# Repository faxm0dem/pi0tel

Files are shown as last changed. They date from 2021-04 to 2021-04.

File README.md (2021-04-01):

# 3615 pi0

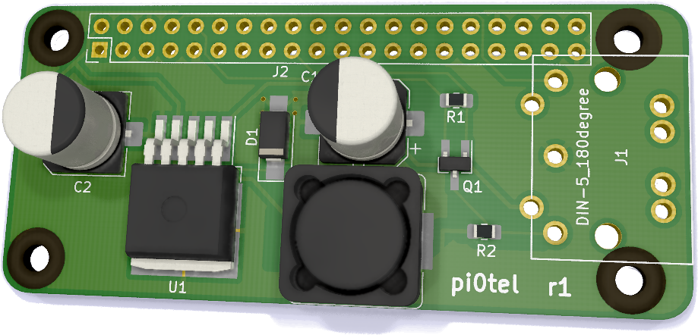
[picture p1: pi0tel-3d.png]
3D Render of the pi0tel pcb


This uHat is designed to plug on top of a pi0 or pi0-w.
It's designed to plug to the DIN-5 at the back of a Minitel-2.
The pi0 will be powered by the Minitel through the Buck converter on
the hat. TX and RX will be level-shifted to the right level on the pi's UART.

The aim is to plug the resulting dongle into a Minitel, and get instant linux.

3615 pi0 (or shall we say, 31415 Minitel).

# Reference

* https://niteshbharadwaj.github.io/posts/raspi_from_battery.html
* http://pila.fr/wordpress/?p=361
* http://www.jelora.fr/post/2020/02/25/Adaptateur-prise-DIN-peri-informatique-Minitel-vers-Serie-RS232-et-Serie-USB.html
* https://www.ti.com/lit/ds/symlink/lm2596.pdf
* https://www.edn.com/pcb-layout-tips-for-thermal-vias/
* https://www.instructables.com/id/Arduino-to-RPi-three-ways-to-convert-5-volts-to-33/
* https://randomnerdtutorials.com/how-to-level-shift-5v-to-3-3v/

# Notes

* Cin and Cout
  - should both have short leads to lm2596
  - should both have low ESR (e.g. high V rating, Nichicon PL, 1.25*Vin = 10V)
  - Ripple current rating 50% of DC load (500mA in our case)
* Cin 270uF or 330uF
* Cout 470/25 Pana or 560/16 Nichi
* Diode
  - current rating = 1.3*load = 800mA
  - reverse V rating = 1.25*Vinmax = 10V
* Heat pad should at least be 0.4"²
* L choice see page 20 of Datasheet
  - L21/L22

||uH|A|SCHOTT|SCHOTT|RENCO|RENCO|PULSE|PULSE|COILCRAFT|
|-|--|-|---|---|-----|-----|-----|-----|---|
|L21|68|0.99|67144070|67144450|RL-5471-5|RL1500-68|PE-53821|PE-53821-S|DO3316-683|
|L22|47|1.17|67144080|67144460|RL-5471-6|—|PE-53822|PE-53822-S|DO3316-47|

* If we want low output ripple we can add post ripple filter 1uH-5uH
  with low DC Resistance and low ESR cap

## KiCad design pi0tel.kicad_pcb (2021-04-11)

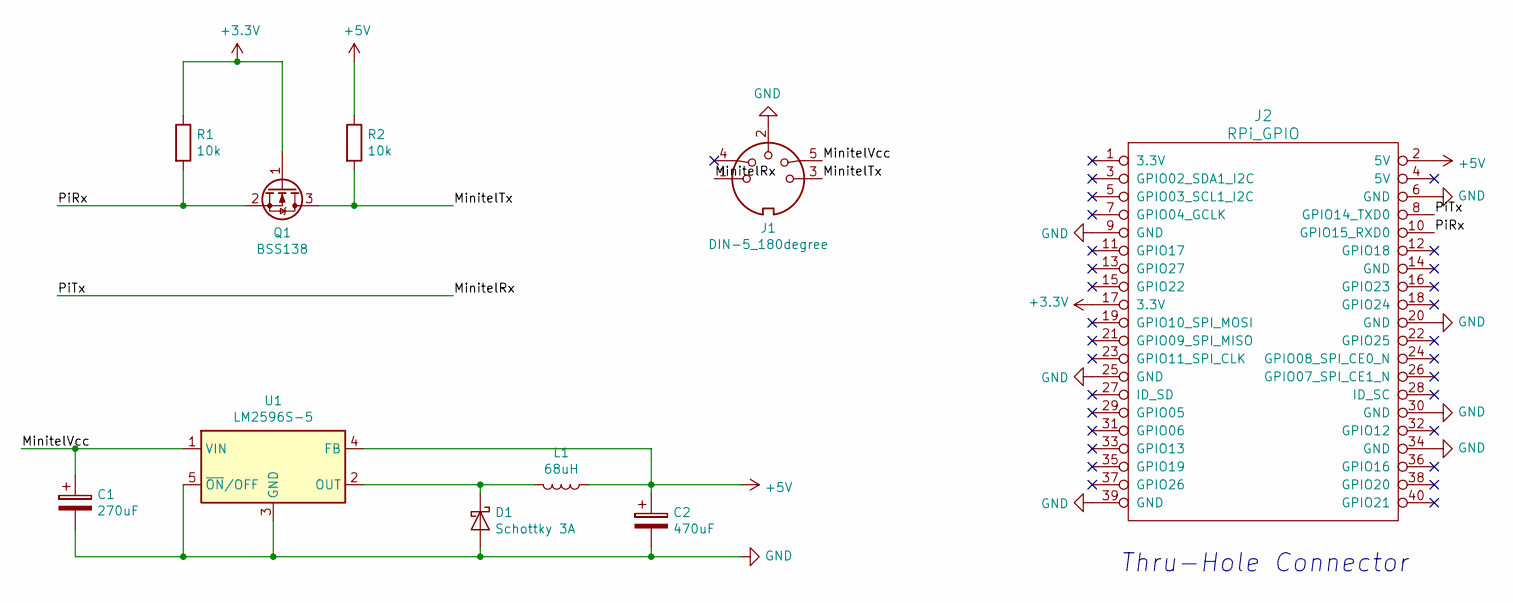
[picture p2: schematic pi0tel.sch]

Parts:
C1: 270uF; CP_Elec_8x10.5
C2: 470uF; CP_Elec_8x10.5
D1: Schottky 3A; D_SMA_Handsoldering
J1: DIN-5_180degree; din_5_econet_pcb_mount
J2: RPi_GPIO; PinHeader_2x20_P2.54mm_Vertical
L1: 68uH; L_1210_3225Metric_Pad1.42x2.65mm_HandSolder
Q1: BSS138; SOT-23_Handsoldering
R1, R2: 10k; R_0805_2012Metric_Pad1.15x1.40mm_HandSolder
U1: LM2596S-5; TO-263-5_TabPin3

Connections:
+3V3: J2.17 (3.3V), Q1.1 (G), R1.1
+5V: C2.1, J2.2 (5V), L1.1, R2.1, U1.4 (FB)
/MinitelRx: J1.1, J2.8 (GPIO14_TXD0)
/MinitelTx: J1.3, Q1.3 (D), R2.2
/MinitelVcc: C1.1, J1.5, U1.1 (VIN)
/PiRx: J2.10 (GPIO15_RXD0), Q1.2 (S), R1.2
GND: C1.2, C2.2, D1.2 (A), J1.2, J2.6 (GND), J2.9 (GND), J2.20 (GND), J2.25 (GND), J2.30 (GND), J2.34 (GND), J2.39 (GND), U1.3 (GND), U1.5 (~ON~/OFF)
unnamed: D1.1 (K), L1.2, U1.2 (OUT)

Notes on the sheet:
Thru-Hole Connector

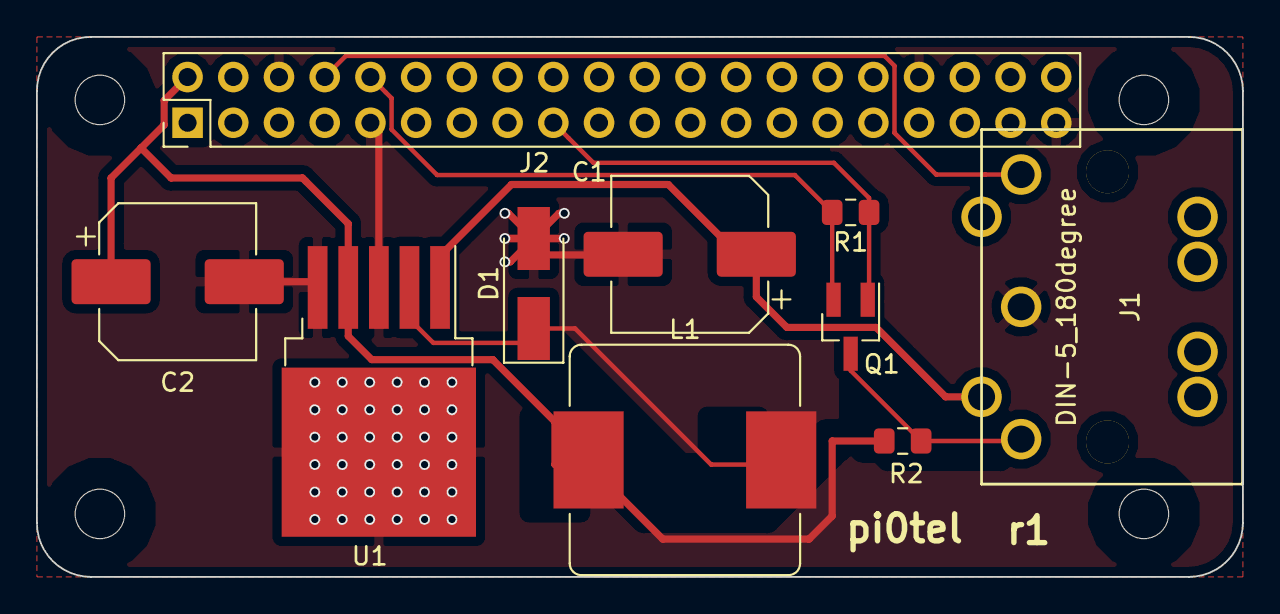
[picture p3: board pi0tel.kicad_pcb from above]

Board: 2 copper layers, 67.0 x 30.0 mm, 10 parts (0 on the bottom side), 8 nets.

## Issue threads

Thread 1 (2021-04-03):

Schottky diode footprint is wrong

faxm0dem, 2021-04-03:
Change footprint to proper Schottky diode's

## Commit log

2020-06-28 add stuff
    [pi0tel.kicad_pcb, pi0tel.sch]
2020-06-30 Add research
    Thermal considerations on PCB design
2020-07-01 getting there
    [pi0tel.kicad_pcb, pi0tel.sch]
2020-07-01 Move din to the back
    [pi0tel.kicad_pcb, pi0tel.sch]
2021-03-13 Put din connector on top side.
    Also a few adjustments
    [pi0tel.kicad_pcb, pi0tel.sch]
2021-03-13 Increase board size to accomodate for DIN
    [pi0tel.kicad_pcb]
2021-03-13 Add some text
    [pi0tel.kicad_pcb]
2021-04-11 Fix footprint for Schottky
    [pi0tel.kicad_pcb, pi0tel.sch]
2021-04-11 Enlarge inductance pads for handsolder
    [pi0tel.kicad_pcb, pi0tel.sch]
2021-04-11 change inductor again now with 3D model
    [pi0tel.kicad_pcb]
